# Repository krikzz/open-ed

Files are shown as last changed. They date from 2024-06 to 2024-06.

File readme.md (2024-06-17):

# Open-ED

Open-ED is a very simple and cheap open source Genesis/Megadrive cartridge.
The cartridge does not have its own processor or FPGA, 
it is built in the old school style using only memory and discrete logic. 
Cartridge design uses an absolute minimum of inexpensive components.

Supported mappers:<br/>
ROM_4M		Most games work in this mode<br/>
ROM_2M+RAM	Some games with battery ram<br/>
ROM_4M+RAM	Beyond Oasis, Sonic-3 etc<br/>

Content description:<br/>
fabrication: pcb gerber files, bill of materials, menu binary<br/>
menu:	menu sources<br/>
pcb_src: pcb sources<br/>
schematic: cartridge schematics<br/>
flashkit-md.exe: flaskit software v1.0.0.1<br/>
open-ed.v: cartridge design in verilog<br/>
open-ed-mapper: cartridge mapper description<br/>
flashkit_mod.jpg: FlashKit mod required for open-ed programming<br/>
open-ed.jpg: cartridge photo<br/>

Menu programming<br/>
open-ed.md should be burned to the upper bank of flash memory (0x400000-0x40FFFF)<br/>
Menu can be programmed to the flash chip using any flash programmer or FlashKit<br/>
FlashKit can program menu onboard (flashkit-md v1.0.0.1 required)<br/>
FlashKit have to be modified: 10k pullup to the cart pin B27(/VRES)<br/>

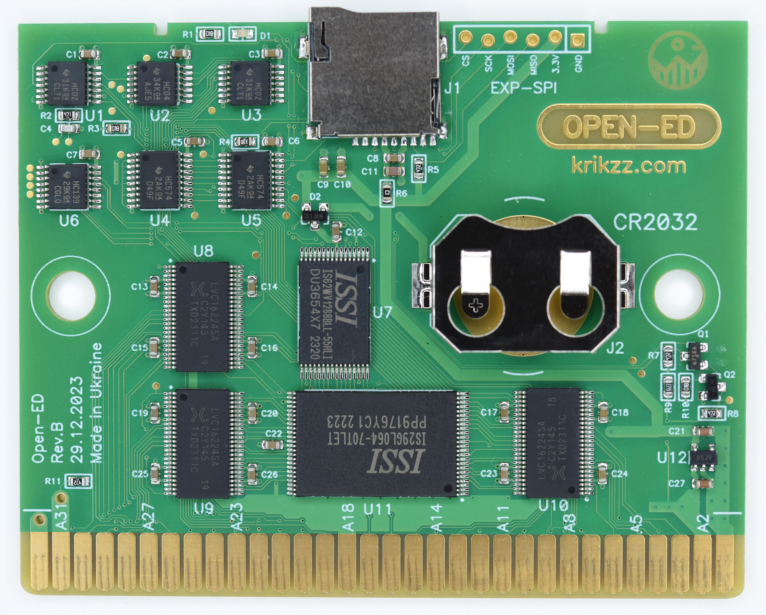
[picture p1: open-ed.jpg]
Open-ED PCB


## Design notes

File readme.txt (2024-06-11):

Open-ED is a very simple and cheap open source Genesis/Megadrive cartridge. 
The cartridge does not have its own processor or FPGA, 
it is built in the old school style using only memory and discrete logic. 
Cartridge design uses an absolute minimum of inexpensive components.

Supported mappers:
ROM_4M		Most games work in this mode
ROM_2M+RAM	Some games with battery ram
ROM_4M+RAM	Beyond Oasis, Sonic-3 etc

Content description:
fabrication: pcb gerber files, bill of materials, menu binary
menu:	menu sources
pcb_src: pcb sources
schematic: cartridge schematics
flashkit-md.exe: flaskit software v1.0.0.1
open-ed.v: cartridge design in verilog
open-ed-mapper: cartridge mapper description
flashkit_mod.jpg: FlashKit mod required for open-ed programming
open-ed.jpg: cartridge photo

Menu programming
open-ed.md should be burned to the upper bank of flash memory (0x400000-0x40FFFF)
Menu can be programmed to the flash chip using any flash programmer or FlashKit.
FlashKit can program menu onboard (flashkit-md v1.0.0.1 required)
FlashKit have to be modified: 10k pullup to the cart pin B27(/VRES)

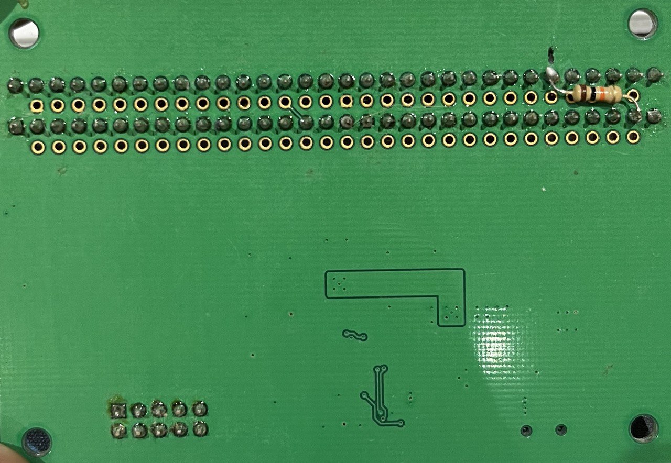
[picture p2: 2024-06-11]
flashkit_mod.jpg

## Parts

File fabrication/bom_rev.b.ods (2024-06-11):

Amount | Part name | Part description | References
2 | SN74HC02PWR | Logic IC | U1,U3
1 | SN74HC04PWR | Logic IC | U2
1 | SN74HC139PWR | Logic IC | U6
2 | SN74HC574PWR | Logic IC | U4,U5
3 | 74LVC162245ADGG | Bus transceivers | U8,U9,U10
1 | M29W064FB70N3E | Flash memory 8MB | U11
1 | MCP1824T-3302E/OT | LDO 3.3v | U12
1 | IS62WV1288BLL-55HLI | Static ram 128KB | U7
1 | SML-D12U8WT86 | led red | D1
1 | BAT54C,215 | Schottky Diodes | D2
1 | SI2307CDS-T1-E3 | MOSFET | Q1
1 | MMBT2222ALT1G | Bipolar Transistors | Q2
1 | Olimex MICRO-SD-CARD | Micro-SD slot | J1
1 | BAT-HLD-001 | CR2032 battery holder | J2
21 | GCJ188R71H104KA12D | Cap 0.1u | C1,C2,C3,C5,C6,C7,C8,C12,C13,C14,C15,C16,C17,C18,C19,C20,C22,C23,C24,C25,C26
3 | GRT188C71C475KE13D | Cap 4.7u | C11,C21,C27
2 | GRT188R61A226ME13D | Cap 22u | C9,C10
1 | GCM1885C2A101JA16D | Cap 100p | C4
1 | AC0603FR-070RL | Res 0r | R6
3 | AC0603FR-101KL | Res 1k | R1,R3,R10
4 | AC0603FR-074K7L | Res 4.7k | R5,R7,R8,R11
1 | AC0603FR-076K2L | Res 6.2k | R9
1 | AC0603FR-0733RL | Res 33r | R4
1 | AC0603FR-07470RL | Res 470r | R2

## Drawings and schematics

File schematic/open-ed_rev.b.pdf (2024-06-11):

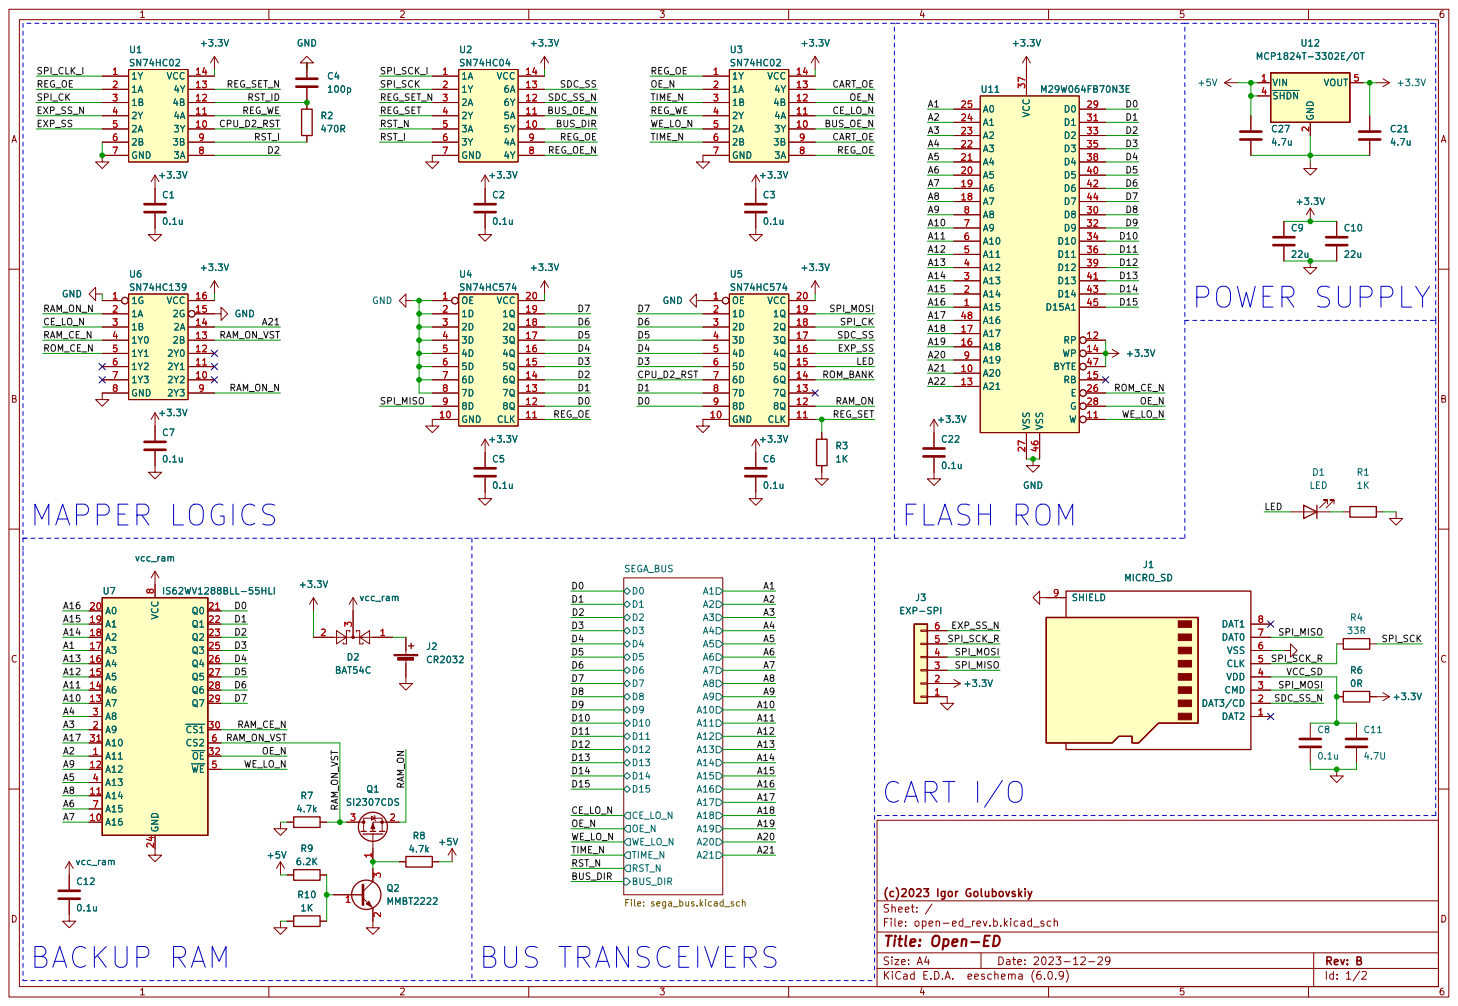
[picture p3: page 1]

File: open-ed_rev.b.kicad_sch Sheet: / (c)2023 Igor Golubovskiy A11A9 A10A6 A18A8A7A4A2A3A5 A12 A13 A20 A21 A19 D3 D2 D11 D9 D10 D5 D12 D4 D13 D8 D0 D1 D6 D7 D14 D15 RST_N

Id: 1/2 Title: Open-ED

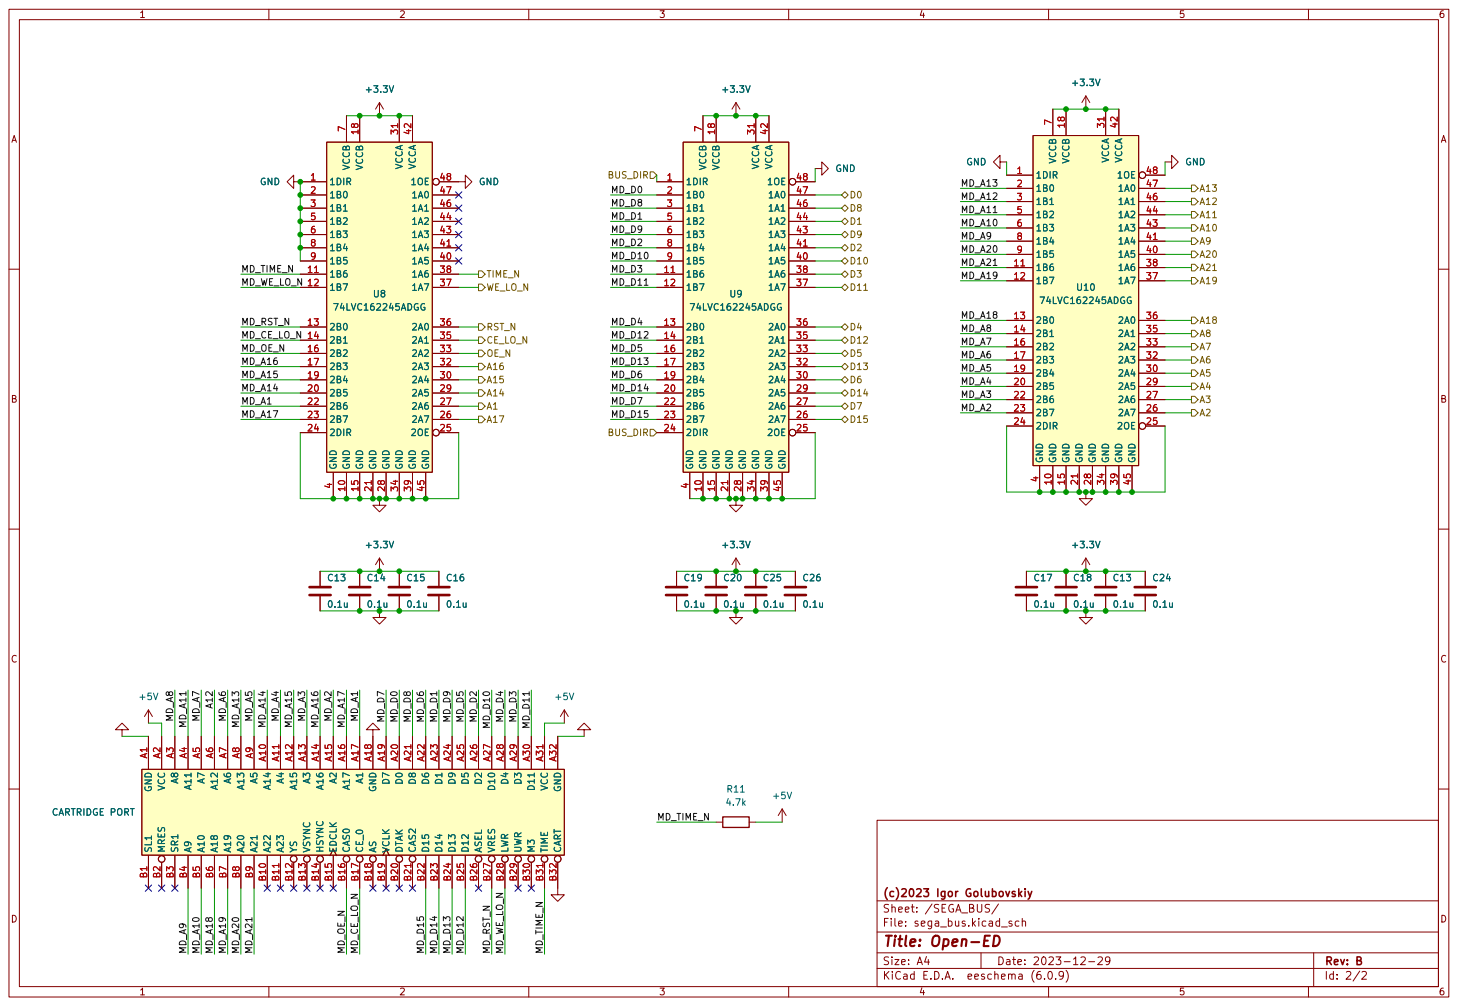
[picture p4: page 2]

(c)2023 Igor Golubovskiy
Sheet: /SEGA_BUS/
File: sega_bus.kicad_sch
Id: 2/2 Title: Open-ED

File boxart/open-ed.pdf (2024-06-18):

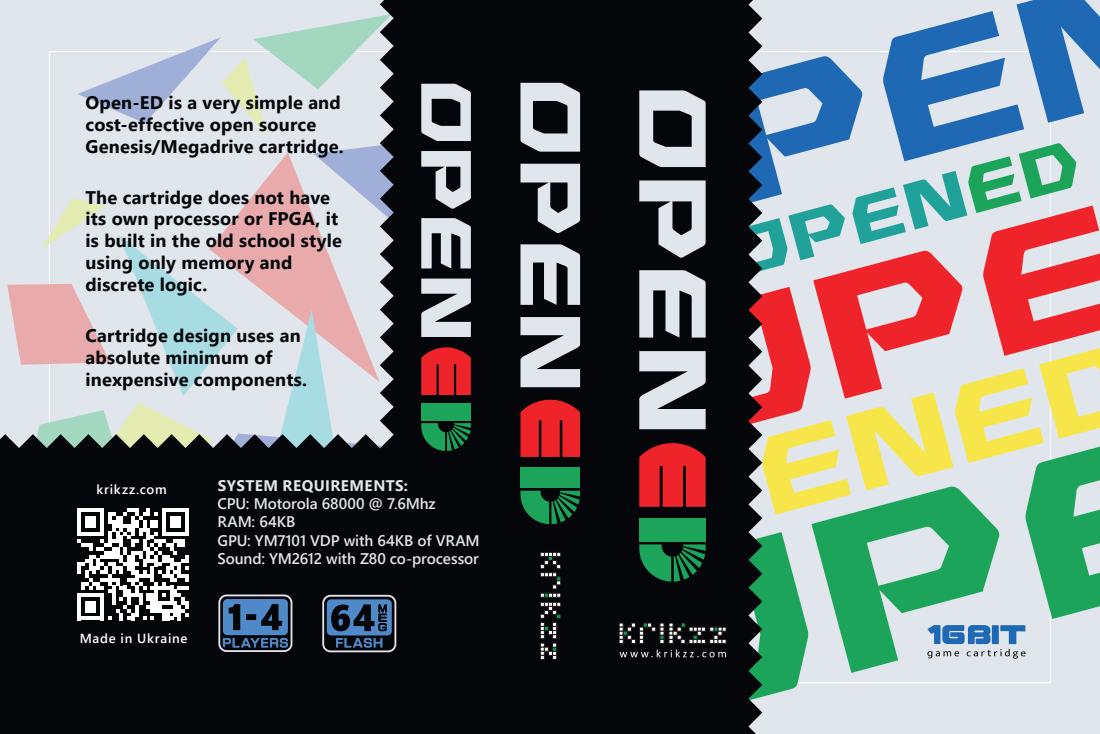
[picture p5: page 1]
OPEN; krikzz.com; PLAYERS; FLASH

Open-ED is a very simple and
cost-effective open source
Genesis/Megadrive cartridge.
The cartridge does not have
its own processor or FPGA, it
is built in the old school style
using only memory and
discrete logic.
Cartridge design uses an
absolute minimum of
inexpensive components.

SYSTEM REQUIREMENTS:
CPU: Motorola 68000 @ 7.6Mhz
RAM: 64KB
GPU: YM7101 VDP with 64KB of VRAM
Sound: YM2612 with Z80 co-processor

Made in Ukraine

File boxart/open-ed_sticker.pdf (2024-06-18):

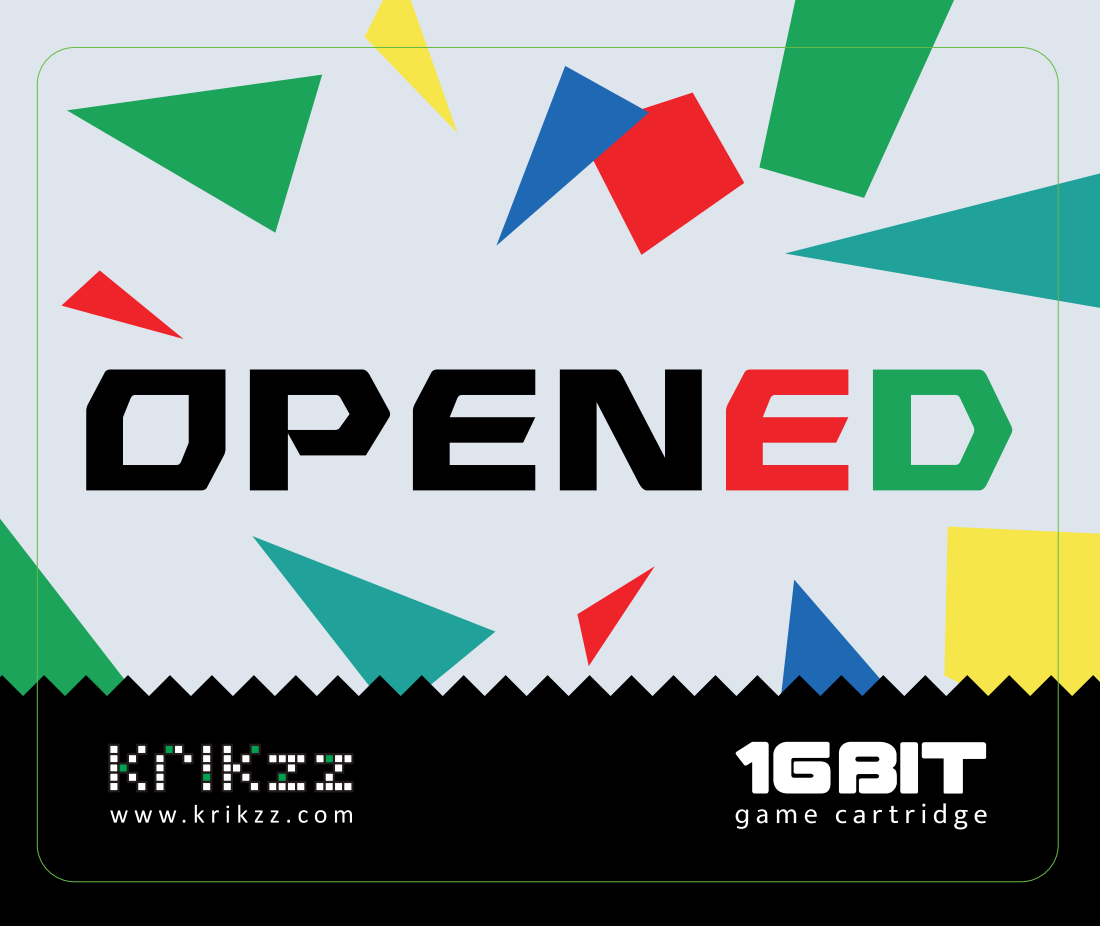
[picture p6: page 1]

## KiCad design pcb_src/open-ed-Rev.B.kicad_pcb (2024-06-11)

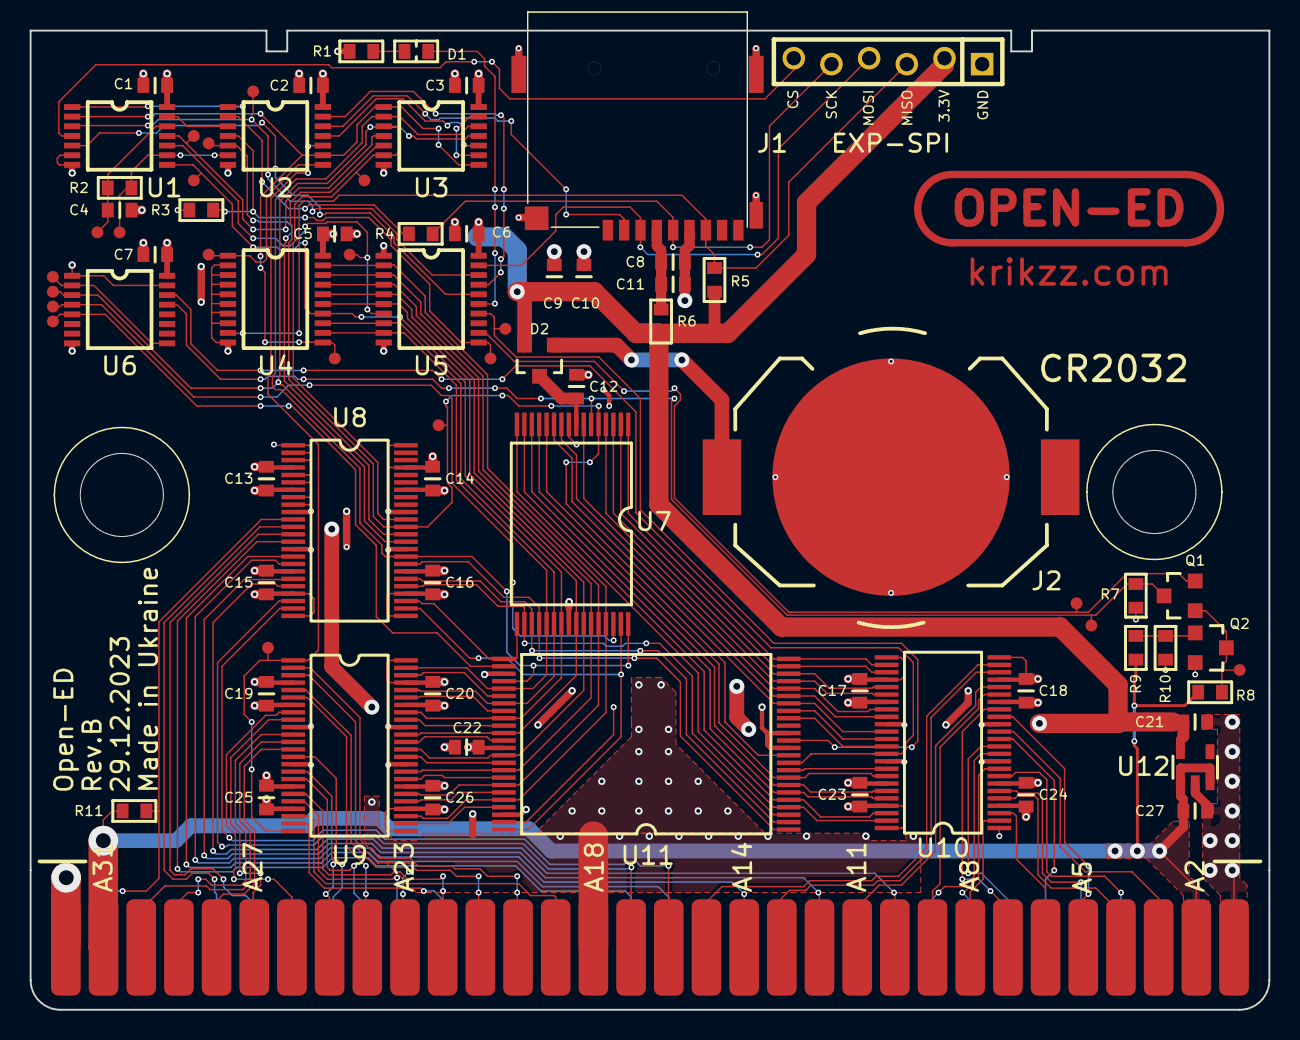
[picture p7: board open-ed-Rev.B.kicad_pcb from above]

Board: 2 copper layers, 83.5 x 66.0 mm, 59 parts (1 on the bottom side), 121 nets.

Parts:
C1, C2, C3, C5, C6, C7, C8, C12, C13, C14, C15, C16, C17, C18, C19, C20, C22, C23, C24, C25, C26: 0.1u GCJ188R71H104KA12D; SMD0603C_1
C4: 100p GCM1885C2A101JA16D; SMD0603C_1
C9, C10: 22u GRT188R61A226ME13D; SMD0603C_1
C11, C21, C27: 4.7u GRT188C71C475KE13D; SMD0603C_1
D1: RED SML-D12U8WT86; SMD0603L_1
D2: BAT54C,215; SMD_TRANS_1
J1: Olimex MICRO-SD-CARD; SD_MINI2_1
J2: BAT-HLD-001; CR2032_THT_1
J3: x; JTAG-ROW_1
Q1: SI2307CDS-T1-E3; MOSFET_SMD_1
Q2: MMBT2222ALT1G; T_MMBT2222_1
R1, R3, R10: 1K AC0603FR-101KL; SMD0603R_1
R2: 470r AC0603FR-07470RL; SMD0603R_1
R4: 33r AC0603FR-0733RL; SMD0603R_1
R5, R7, R8, R11: 4.7k AC0603FR-074K7L; SMD0603R_1
R6: 0r AC0603FR-070RL; SMD0603R_1
R9: 6.2K AC0603FR-076K2L; SMD0603R_1
SEGA1: x; SEGA_CART_TOP_1
SEGA2: x; SEGA_CART_BOT_1
U1, U3: SN74HC02PWR; 74HC02_TSSOP_1
U2: SN74HC04PWR; 74HC04_TSSOP_1
U4, U5: SN74HC574PWR; 74HC573_TSSOP_1
U6: SN74HC139PWR; 74HC139_TSSOP_1
U7: IS62WV1288BLL-55HLI; TS0P32_1
U8, U9, U10: 74LVC162245ADGG; SN74LVTH162245D_1
U11: M29W064FB70N3E; M29W640_1
U12: 3.3v MCP1824T-3302E/OT; MCP1824_1

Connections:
A1: U7.a3, U8.2a7, U11.A1
A2: U7.a11, U10.2a8, U11.A2
A3: U7.a9, U10.2a7, U11.A3
A4: U7.a8, U10.2a6, U11.A4
A5: U7.a13, U10.2a5, U11.A5
A6: U7.a15, U10.2a4, U11.A6
A7: U7.a16, U10.2a3, U11.A7
A8: U7.a14, U10.2a2, U11.A8
A9: U7.a12, U10.1a5, U11.A9
A10: U7.a7, U10.1a4, U11.A10
A11: U7.a6, U10.1a3, U11.A11
A12: U7.a5, U10.1a2, U11.A12
A13: U7.a4, U10.1a1, U11.A13
A14: U7.a2, U8.2a6, U11.A14
A15: U7.a1, U8.2a5, U11.A15
A16: U7.a0, U8.2a4, U11.A16
A17: U7.a10, U8.2a8, U11.A17
A18: U10.2a1, U11.A18
A19: U10.1a8, U11.A19
A20: U10.1a6, U11.A20
A21: U6.2a0, U10.1a7, U11.A21
BUS_DIR: U2.5y, U9.1dir, U9.2dir
BUS_OE_N: U2.5a, U3.3y
CART_OE: U3.3b, U3.4y
CE_LO_N: U3.4a, U6.1a1, U8.2a2
CPU_D2_RST: U1.3y, U5.d5
D0: U4.q7, U5.d7, U7.d0, U9.1a1, U11.D0
D1: U4.q6, U5.d6, U7.d1, U9.1a3, U11.D1
D2: U1.3a, U4.q5, U7.d2, U9.1a5, U11.D2
D3: U4.q4, U5.d4, U7.d3, U9.1a7, U11.D3
D4: U4.q3, U5.d3, U7.d4, U9.2a1, U11.D4
D5: U4.q2, U5.d2, U7.d5, U9.2a3, U11.D5
D6: U4.q1, U5.d1, U7.d6, U9.2a5, U11.D6
D7: U4.q0, U5.d0, U7.d7, U9.2a7, U11.D7
D8: SEGA2.d8, U9.1b2
D9: U9.1a4, U11.D9
D10: U9.1a6, U11.D10
D11: U9.1a8, U11.D11
D12: U9.2a2, U11.D12
D13: U9.2a4, U11.D13
D14: U9.2a6, U11.D14
D15: U9.2a8, U11.D15A0
EXP_SS: U1.2a, U5.q3
EXP_SS_N: J3.gnd, U1.2y
GND: C1.1, C2.1, C3.1, C4.1, C5.2, C6.1, C7.1, C8.1, C9.1, C10.1, C11.1, C12.1, C13.2, C14.2, C15.1, C16.1, C17.2, C18.2, C19.2, C20.2, C21.2, C22.1, C23.1, C24.1, C25.1, C26.1, C27.2, J1.10, J1.11, J1.14, J1.15, J1.gnd, J2.3, J3.tdo, Q2.2e, R1.1, R3.2, R7.2, R10.1, SEGA1.cart, SEGA2.gnd1, SEGA2.gnd2, SEGA2.gnd3, U1.2b, U1.gnd, U2.gnd, U3.gnd, U4.d0, U4.d1, U4.d2, U4.d3, U4.d4, U4.d5, U4.d6, U4.gnd, U5.gnd, U5.oe, U6.1e, U6.2e, U6.gnd, U7.gnd, U7.nc, U8.1b1, U8.1b2, U8.1b3, U8.1b4, U8.1b5, U8.1b6, U8.1dir, U8.2dir, U8.gnd1, U8.gnd2, U8.gnd3, U8.gnd4, U8.gnd5, U8.gnd6, U8.gnd7, U8.gnd8, U8.~1oe, U8.~2oe, U9.gnd1, U9.gnd2, U9.gnd3, U9.gnd4, U9.gnd5, U9.gnd6, U9.gnd7, U9.gnd8, U9.~1oe, U9.~2oe, U10.1dir, U10.2dir, U10.gnd1, U10.gnd2, U10.gnd3, U10.gnd4, U10.gnd5, U10.gnd6, U10.gnd7, U10.gnd8, U10.~1oe, U10.~2oe, U11.GND, U11.GND1, U12.gnd
LED: D1.2, U5.q4
MD_A1: SEGA2.a0, U8.2b7
MD_A2: SEGA2.a1, U10.2b8
MD_A3: SEGA2.a2, U10.2b7
MD_A4: SEGA2.a3, U10.2b6
MD_A5: SEGA2.a4, U10.2b5
MD_A6: SEGA2.a5, U10.2b4
MD_A7: SEGA2.a6, U10.2b3
MD_A8: SEGA2.a7, U10.2b2
MD_A9: SEGA1.a8, U10.1b5
MD_A10: SEGA1.a9, U10.1b4
MD_A11: SEGA2.a10, U10.1b3
MD_A12: SEGA2.a11, U10.1b2
MD_A13: SEGA2.a12, U10.1b1
MD_A14: SEGA2.a13, U8.2b6
MD_A15: SEGA2.a14, U8.2b5
MD_A16: SEGA2.a15, U8.2b4
MD_A17: SEGA2.a16, U8.2b8
MD_A18: SEGA1.a17, U10.2b1
MD_A19: SEGA1.a18, U10.1b8
MD_A20: SEGA1.a19, U10.1b6
MD_A21: SEGA1.a20, U10.1b7
MD_CE_LO_N: SEGA1.~ce_l, U8.2b2
MD_D0: SEGA2.d0, U9.1b1
MD_D1: SEGA2.d1, U9.1b3
MD_D2: SEGA2.d2, U9.1b5
MD_D3: SEGA2.d3, U9.1b7
MD_D4: SEGA2.d4, U9.2b1
MD_D5: SEGA2.d5, U9.2b3
MD_D6: SEGA2.d6, U9.2b5
MD_D7: SEGA2.d7, U9.2b7
MD_D8: U9.1a2, U11.D8
MD_D9: SEGA2.d9, U9.1b4
MD_D10: SEGA2.d10, U9.1b6
MD_D11: SEGA2.d11, U9.1b8
MD_D12: SEGA1.d12, U9.2b2
MD_D13: SEGA1.d13, U9.2b4
MD_D14: SEGA1.d14, U9.2b6
MD_D15: SEGA1.d15, U9.2b8
MD_OE_N: SEGA1.~oe, U8.2b3
MD_RST_N: SEGA1.~rst, U8.2b1
MD_TIME_N: R11.2, SEGA1.time, U8.1b7
MD_WE_LO_N: SEGA1.~wel, U8.1b8
NET00001: D1.1, R1.2
NET00010: Q2.1b, R9.2, R10.2
OE_N: U3.1a, U3.4b, U7.oe, U8.2a3, U11.OE
RAM_CE_N: U6.1s0, U7.nce
RAM_ON: Q1.2_s, U5.q7
RAM_ON_N: U6.1a0, U6.2s3
RAM_ON_VST: Q1.3_d, R7.1, U6.2a1, U7.ce2
REG_OE: U1.1a, U2.4a, U3.1y, U3.3a, U4.le
REG_OE_N: U2.4y, U4.oe
REG_SET: R3.1, U2.2y, U5.le
REG_SET_N: U1.4y, U2.2a
REG_WE: U1.4a, U3.2y
ROM_BANK: U5.q5, U11.A22
ROM_CE_N: U6.1s1, U11.CE
RST_I: R2.1, U1.3b, U2.3y
RST_ID: C4.2, R2.2, U1.4b
RST_N: U2.3a, U8.2a1
SDC_SS: U2.6a, U5.q2
SDC_SS_N: J1.ss, U2.6y
SPI_CK: U1.1b, U5.q1
SPI_MISO: J1.miso, J3.tck, R5.2, U4.d7
SPI_MOSI: J1.mosi, J3.tdi, U5.q0
SPI_SCK: R4.1, U2.1y
SPI_SCK_I: U1.1y, U2.1a
SPI_SCK_R: J1.clk, J3.tms, R4.2
TIME_N: U3.1b, U3.2b, U8.1a7
VBAT: D2.3, J2.2
VCC3: C1.2, C2.2, C3.2, C5.1, C6.2, C7.2, C9.2, C10.2, C13.1, C14.1, C15.2, C16.2, C17.1, C18.1, C19.1, C20.1, C21.1, C22.2, C23.2, C24.2, C25.2, C26.2, D2.2, J3.vcc, R5.1, R6.1, U1.vcc, U2.vcc, U3.vcc, U4.vcc, U5.vcc, U6.vcc, U8.vcc1, U8.vcc2, U8.vcc3, U8.vcc4, U9.vcc1, U9.vcc2, U9.vcc3, U9.vcc4, U10.vcc1, U10.vcc2, U10.vcc3, U10.vcc4, U11.BYTE, U11.RST, U11.VCC, U11.WP, U12.vout
VCC5: C27.1, R8.2, R9.1, R11.1, SEGA2.vcc1, SEGA2.vcc2, U12.shdn, U12.vin
VCC_RAM: C12.2, D2.1, U7.vcc
VCC_SD: C8.2, C11.2, J1.vcc, R6.2
VCC_STB_N: Q1.1_g, Q2.3c, R8.1
WE_LO_N: U3.2a, U7.we, U8.1a8, U11.WE

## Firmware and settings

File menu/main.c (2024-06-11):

#include "main.h"


void mainInit();
void printError(u8 error);

int main() {

    u8 resp;

    mainInit();


    while (1) {

        resp = edInit();

        if (resp) {
            printError(resp);
            continue;
        }

        resp = fmanager();
        printError(resp);
    }


    return 0;
}

void mainInit() {

    static u16 pal_std[] = {
        0x000, 0x444, 0x000, 0x000, 0x000, 0x000, 0x000, 0x000, 0x000, 0x000, 0x000, 0x000, 0x000, 0x000, 0x000, 0xAAA,
        0x000, 0x444, 0x000, 0x000, 0x000, 0x000, 0x000, 0x000, 0x000, 0x000, 0x000, 0x000, 0x000, 0x000, 0x000, 0xFFF,
        0x000, 0x444, 0x000, 0x000, 0x000, 0x000, 0x000, 0x000, 0x000, 0x000, 0x000, 0x000, 0x000, 0x000, 0x000, 0x2cc,
        0x000, 0x444, 0x000, 0x000, 0x000, 0x000, 0x000, 0x000, 0x000, 0x000, 0x000, 0x000, 0x000, 0x000, 0x000, 0x0F0
    };

    sysInit(G_MODE_320x224, 64, 32);
    for (u16 i = 0; i < 16 * 4; i++) {
        gSetColor(i, pal_std[i]);
    }
    gCleanPlan();
}

void printError(u8 error) {

    extern u8 dresp;

    gCleanPlan();
    gSetPal(0);
    gSetXY(G_SCREEN_W / 2 - 6, G_SCREEN_H / 2 - 1);

    gConsPrint("ERROR: ");
    gAppendHex8(error);
    if (error < 19) {//disk error details
        gAppendString(":");
        gAppendHex8(dresp);
    }

    sysJoyWait();
}

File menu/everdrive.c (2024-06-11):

#include "main.h"
#include "flash.h"

//control register
#define CTRL_REG        *((vu16 *) 0xA130E0)


//ctrl write
#define CTRL_SRM_ON     0x01// 4MB ROM ro 2MB ROM + 128KB SRAM
#define CTRL_RESERVED   0x02// unused
#define CTRL_ROM_BANK   0x04// ROM bank select (1=MENU or 0=GAME)
#define CTRL_LED        0x08// led controll
#define CTRL_EXP_SS     0x10// expansion SPI chip select
#define CTRL_SDC_SS     0x20// SD card chip select (SPI)
#define CTRL_SPI_CLK    0x40// SD card clock
#define CTRL_SPI_MOSI   0x80// SD card data input


//ctrl read
#define CTRL_SPI_MISO   0x01// SD card data output

//SPI_CLK can be clocked automatically at each read of CTRL_REG
//SPI_CLK should be set in 0 for autoclocking

void spi_r_512(void *dst);
void edLoadInfo();


u16 ed_cfg;
DeviceInfo dev_inf;

u8 edInit() {

    u8 resp;

    edSetBank(BANK_GAME);
    edSetLed(OFF);
    edSetSRAM(OFF);

    flashInit();

    edLoadInfo();

    resp = fsInit();
    if (resp)return resp;

    return 0;
}

void edSetBank(u16 bank) {

    switch (bank) {
        case BANK_GAME:
            ed_cfg &= ~CTRL_ROM_BANK;
            break;
        case BANK_MENU:
            ed_cfg |= CTRL_ROM_BANK;
            break;
    }

    CTRL_REG = ed_cfg;
}

void edSetLed(u8 on) {

    if (on) {
        ed_cfg |= CTRL_LED;
    } else {
        ed_cfg &= ~CTRL_LED;
    }

    CTRL_REG = ed_cfg;
}

void edSetSRAM(u8 on) {

    if (on) {
        ed_cfg |= CTRL_SRM_ON;
    } else {
        ed_cfg &= ~CTRL_SRM_ON;
    }

    CTRL_REG = ed_cfg;

}

void edLoadInfo() {

    edSetBank(BANK_MENU);
    dev_inf.cart_date = swap16(*(vu16 *) (ADDR_CART_DATE + 0));
    dev_inf.cart_time = swap16(*(vu16 *) (ADDR_CART_DATE + 2));
    dev_inf.menu_date = swap16(*(vu16 *) (ADDR_MENU_DATE + 0));
    dev_inf.menu_time = swap16(*(vu16 *) (ADDR_MENU_DATE + 2));
    edSetBank(BANK_GAME);

    dev_inf.flash_type = flashType();

}
//****************************************************************************** spi

u8 spi_rw(u8 val) {

    u8 ret = 0;

    for (u16 i = 0; i < 8; i++) {

        CTRL_REG = (val & CTRL_SPI_MOSI) | ed_cfg;
        CTRL_REG = (val & CTRL_SPI_MOSI) | ed_cfg | CTRL_SPI_CLK;
        ret <<= 1;
        ret |= CTRL_REG;
        CTRL_REG = (val & CTRL_SPI_MOSI) | ed_cfg;
        val <<= 1;
    }

    return ret;
}

u8 spi_r() {

    u8 ret = 0;

    CTRL_REG = ed_cfg | CTRL_SPI_MOSI;

    for (u16 i = 0; i < 8; i++) {

        CTRL_REG = ed_cfg | CTRL_SPI_MOSI | CTRL_SPI_CLK;
        ret <<= 1;
        ret |= CTRL_REG;
        CTRL_REG = ed_cfg | CTRL_SPI_MOSI;
    }

    return ret;
}

void spi_w(u8 val) {

    for (u16 i = 0; i < 8; i++) {

        CTRL_REG = ed_cfg | (val & CTRL_SPI_MOSI);
        CTRL_REG = ed_cfg | (val & CTRL_SPI_MOSI) | CTRL_SPI_CLK;
        CTRL_REG = ed_cfg | (val & CTRL_SPI_MOSI);
        val <<= 1;
    }
}

void spi_select(u8 target) {

    ed_cfg &= ~(CTRL_SDC_SS | CTRL_EXP_SS);

    if (target == SPI_SEL_SDC) {
        ed_cfg |= CTRL_SDC_SS;
    } else if (target == SPI_SEL_EXP) {
        ed_cfg |= CTRL_EXP_SS;
    }

    CTRL_REG = ed_cfg;
}

u8 spi_to_ram(void *dst, u8 slen) {

    u8 *dst8 = (u8 *) dst;
    u16 i;

    while (slen--) {

        spi_w(0xff);

        for (i = 1; i; i++) {
            if (spi_r() == 0xFE)break;
        }
        if (i == 0)return DISK_ERR_RD2;

        spi_r_512(dst8);
        dst8 += 512;

        spi_w(0xff);
        spi_w(0xff);
    }

    return 0;
}
//******************************************************************************

u8 edLoadROM(u8 *path) {

    u8 resp;
    u32 size;
    u8 buff[MAX_BUFF_SIZE];

    gCleanPlan();

    resp = fileOpen(path, FA_READ);
    if (resp)return resp;

    size = fileAvailable();
    if (size > MAX_ROM_SIZE) {
        size = MAX_ROM_SIZE;
    }

    gProgressBar(size, sizeof (buff), 0);

    edSetBank(BANK_GAME);

    for (u32 i = 0; i < size;) {

        u16 block = sizeof (buff);
        if (i + block > size) {
            block = size - i;
        }

        if (i % 0x10000 == 0) {
            flashErase64K(i, 0);
        }

        resp = fileRead(buff, block);
        if (resp)return resp;

        flashWrite((u16 *) buff, (u16 *) i, block);

        i += sizeof (buff);
        gProgressBar(size, block, i);

    }

    resp = fileClose();
    if (resp)return resp;

    return 0;
}

void edStartROM(u8 stop_disk) {

    if (stop_disk) {
        diskStop();
    }
    edSetBank(BANK_GAME);

    VDP_CTRL16 = 0x8006;
    VDP_CTRL16 = 0x8104;

    *(vu8 *) 0xa10009 = 0;
    *(vu8 *) 0xa1000b = 0;
    *(vu8 *) 0xa1000d = 0;

    asm("move.l 0, %sp");
    asm("move.l 4, %a0");
    asm("jmp (%a0)");
}

u8 edIsUpdateRom() {

    u8 *ref_str = "OPEN-EVERDRIVE";
    u8 *rom_str = (u8 *) 0x120;

    for (u16 i = 0; ref_str[i] != 0; i++) {
        if (ref_str[i] != rom_str[i]) {
            return 0;
        }
    }

    return 1;
}

void edUpdateMenu() {

    u8 datetime[4];
    u8 buff[MAX_BUFF_SIZE];
    u32 size = 0x10000;

    edSetBank(BANK_MENU);
    mem_copy(datetime, (void *) ADDR_CART_DATE, 4);

    gProgressBar(size, sizeof (buff), 0);
    flashErase64K(0, 1);

    for (u32 i = 0; i < size;) {

        u16 block = sizeof (buff);
        if (i + block > size) {
            block = size - i;
        }

        edSetBank(BANK_GAME);
        mem_copy(buff, (void *) i, block);
        edSetBank(BANK_MENU);

        if (i == 0) {
            //restore manufacturing date
            mem_copy(&buff[ADDR_CART_DATE], datetime, 4);
        }

        flashWrite((u16 *) buff, (u16 *) i, block);

        i += sizeof (buff);
        gProgressBar(size, block, i);
    }

    edReboot();
}

void edReboot() {

    diskStop();
    edSetBank(BANK_MENU);
    asm("move.l 4, %a0");
    asm("jmp (%a0)");
}
